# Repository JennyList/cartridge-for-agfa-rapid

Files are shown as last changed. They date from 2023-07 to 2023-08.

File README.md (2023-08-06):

# Cartridge For Agfa Rapid Cameras
A 3D-printable film cartridge for Agfa Rapid film cameras

The Rapid film system was Agfa's answer to Kodak's 126 cartridge back in the 1960s, a quick-loading 35mm film format. It was based on an earlier Agfa cartridge, with the addition of a tab to select film speed.

This is a 3D-printable Rapid cartridge, which can be loaded with 35mm film. The STL is for an ISO 100 cartridge, while examining the OpenSCAD file you'll find any of the available ISO settings can be selected.

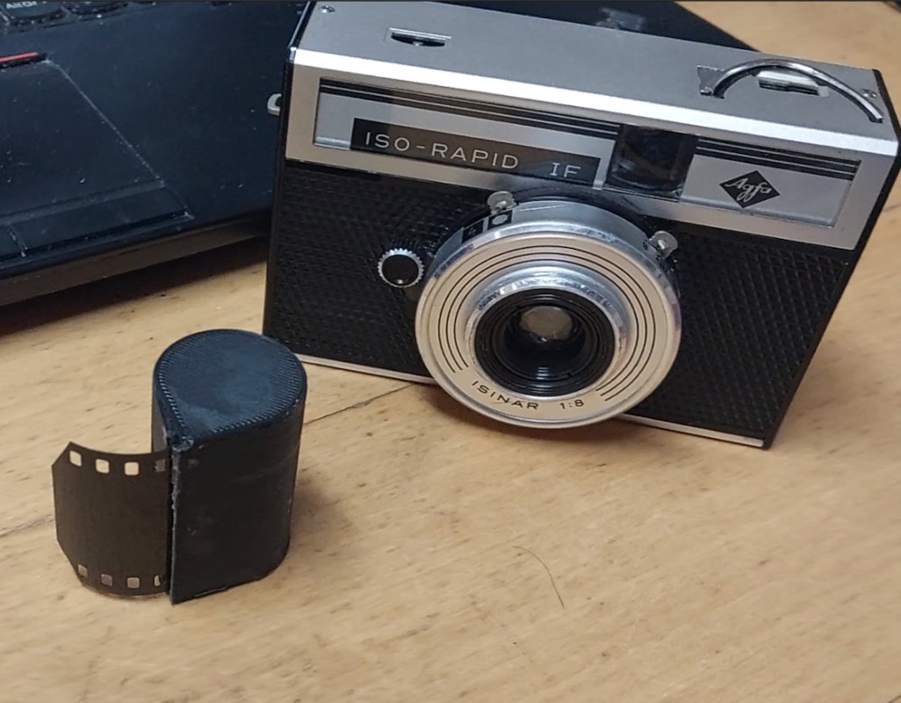
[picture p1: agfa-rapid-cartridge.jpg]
The cartridge, with an Agfa Rapid camera in the background


The cartridge and lids should be printed, then a set of two felt light seals should be glued along the opposite sides of the film opening. I used the soft side of a piece of black velcro, but a strip of black felt can also be used. Use a knife blade to keep the two felt pieces from sticking to each other. Once the glue has set, the felt can be trimmed at each end and the end pieces can be glued into place.

The cartridge should be loaded with a piece of 35mm film about 70cm long, on which should fit the 12 exposures of a Rapid film. The film has to coil up in the cartridge, so it can't take much more film than this. I strongly recommend passing the end of the film into the take-up cartridge when you load the camera, rather than relying on Agfa's quick-load feature in which the film is supposed to feed into the cartridge.

I've put up [a YouTube video with much more](https://www.youtube.com/watch?v=byiobFTktFw).

Comprehensive information on Agfa Rapid film can be found on [this German Wikipedia page](https://de.wikipedia.org/wiki/Agfa_Rapid)

## Licence

This model is licensed under the [Creative Commons Attribution Share Alike 4.0 International licence](license.md).

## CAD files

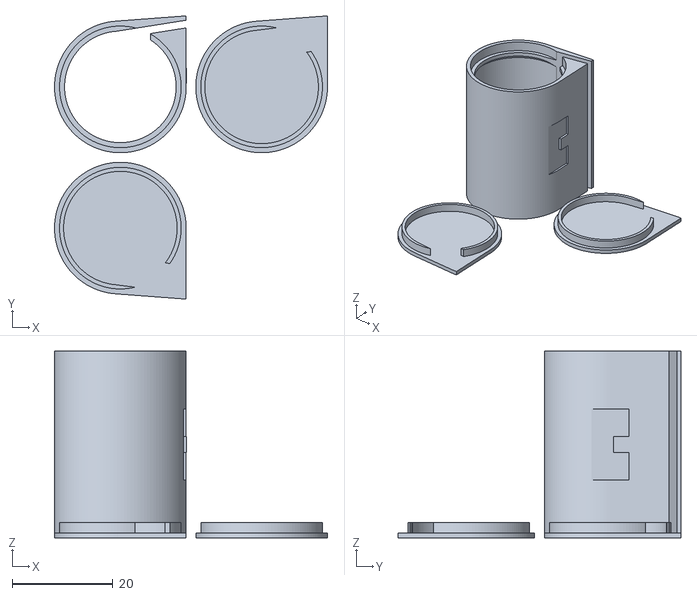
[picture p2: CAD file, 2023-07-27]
agfa-rapid.stl
54.1 x 56.1 x 37.0

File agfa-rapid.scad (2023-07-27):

/*
A cartridge for Agfa Rapid cameras
Jenny List 2023
CC-BY-SA 4.0

At the bottom of the file you'll find the commands to render the parts you'll need.

RapidCartridge(iso) is the cartridge shell. Look at the code for ISOtab() for values of iso.

RapidCartridgeLid() is the cartridge end. You'll need two of these mirrored.

These two functions are internal.
FilmSlideRing() is the ring inside the cartridge to reduce friction
ISOtab(iso=25) is the tab component
*/


module FilmSlideRing(){ //thin ring for film to slide on
    difference(){
        cylinder(2,13.05,13.05,$fn=120,true);
        //translate([0,0,1]) cylinder(1,11.05,12.05,$fn=120,true); //upper bevel
        translate([0,0,0.5])cylinder(1,11.05,11.05,$fn=120,true); //main ring
        translate([0,0,-0.5]) cylinder(1,12.05,11.05,$fn=120,true); //lower bevel for 3d printing
    }
}

module ISOtab(iso=25){
    if(iso==25){
        //tabLength is 0;
        //render nothing
    }
    if(iso==32){
        translate([0,-0.25,0]) cube([1,0.5,3.2],true);
    }
    if(iso==40){
        translate([0,-0.5,0]) cube([1,1,3.2],true);
    }
    if(iso==50){
        translate([0,-0.75,0]) cube([1,1.5,3.2],true);
    }
    if(iso==65){
        translate([0,-1,0]) cube([1,2,3.2],true);
    }
    if(iso==80){
        translate([0,-1.25,0]) cube([1,2.5,3.2],true);
    }
    if(iso==100){
        translate([0,-1.5,0]) cube([1,3,3.2],true);
    }
    if(iso==125){
        translate([0,-1.75,0]) cube([1,3.5,3.2],true);
    }
    if(iso==160){
        translate([0,-2,0]) cube([1,4,3.2],true);
    }
    if(iso==200){
        translate([0,-2.25,0]) cube([1,4.5,3.2],true);
    }
    if(iso==250){
        translate([0,-2.5,0]) cube([1,5,3.2],true);
    }
    if(iso==320){
        translate([0,-2.75,0]) cube([1,5.5,3.2],true);
    }
    if(iso==400){
        translate([0,-3,0]) cube([1,6,3.2],true);
    }
}

module RapidCartridgeLid(){
    difference(){
        union(){
            cylinder(1,13.05,13.05,$fn=120,true); //flat lid
            translate([12.55,7,0])cube([1,14,1],true); //tangent at right angles
            rotate([0,0,4.3]) translate([7,12.55,0])cube([13,1,1],true); //tangent at a slight angle.
            translate([6.5,6.5,0]) cube([13,13,1],true); //Cube to fill in the hole
            translate([0,0,1.5]) cylinder(2,12.05,12.05,$fn=120,true);// protrusion
        }
        translate([0,0,1.5]) cylinder(2,11.25,11.25,$fn=120,true); //carve out the middle.
        rotate([0,0,7]) translate([7,8.5,1.5])cube([13,5.5,2],true); //tangent at a slight angle.
    }
}

module RapidCartridge(iso=25){
    difference(){
        union(){
            difference(){
                union(){
                    cylinder(37,13.05,13.05,$fn=120,true); //main cylinder
                    translate([12.55,7,0])cube([1,14,37],true); //tangent at right angles
                    rotate([0,0,4.3]) translate([7,12.55,0])cube([13,1,37],true); //tangent at a slight angle.
                    translate([6.5,6.5,0]) cube([13,13,37],true); //Cube to fill in the hole
                }
                cylinder(37,12.05,12.05,$fn=120,true);  //Carve out space for film
                translate([13.2,-1.3,0])cube([1.4,10,14],true); //iso space
            }
            // Rings to reduce friction on film
            translate([0,0,15]) FilmSlideRing();
            translate([0,0,-15]) FilmSlideRing();
            translate([12.6,3.7,0]) ISOtab(iso); //ISO tab
        }
        rotate([0,0,9]) translate([7,10.25,0])cube([16,1.5,37],true); //film guide
        translate([5,10,0])cube([2,2,37],true);//remove pointed ends on rings
    }
}

translate([0,0,18.5]) RapidCartridge(100);
translate([28,0,0.5]) RapidCartridgeLid();
mirror ([0,1,0]) translate([0,28,0.5]) RapidCartridgeLid();
